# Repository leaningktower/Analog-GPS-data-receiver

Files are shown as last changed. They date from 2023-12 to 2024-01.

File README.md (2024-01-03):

Pasted Graphic

The picture above shows a pure analog Global Positioning System (GPS) data receiver that can receive the Navigation (NAV) Message from the GPS satellite. The receiver is a dual conversion receiver that includes five homemade PCB boards. A tinyFPGA is used for generating the Coarse Acquisition (C/A) code which retrieve the direct-sequence spread spectrum (DSSS) GPS signal submerged below the thermal noise level.

I was originally motivated by the works [1, 2] of Matjaz Vidmar (S53MV) and Andrew Holme. Both of the receivers are based on the 1-bit analog-to-digital converter (ADC) structure that uses on a single comparator that greatly the hardware of the design. The receiver of S53MV was built more than 30 years ago, based on a digital signal processor (DSP) that is made from fully discreet logic chips and a MC68010 processor. And the receiver of Andrew Holme is based on FPGA with a Forth-like Embedded CPU and a Raspberry Pi in charge of the fast Fourier transform (FFT) to speed up the satellite tracking process. Both two projects include great amount of minor details in software make them a bit daunted to the people who wants to learn from it and build their own receiver.

Another impressive analog GPS receiver comes from the book [3] of Dan Doberstein. In the Chapter 7 of this book, he provides a very detailed description of the GPS100SC receiver, which is a single channel data receiver and you can still literally build four of these receivers and find out your position! However, the receiver is not fully open sourced but makes me feel excited to build my own receiver from scratch. As a fan of analog electronics, it is also a fun project!

### Hardware Architecture

Pasted Graphic 1

The block diagram of the receiver is shown above. The receiver includes 5 different parts, the 1st mixer board, 1st LO board, 2nd mixer and correlation board, IF signal processing board and FPGA interfacing board (not shown). They are indicated by the dashed blocks in the diagram.

A commercial GPS antenna with internal amplifier and filters is used that can be easily find on AliExpress and Amazon. The first IF is set to around 60 MHz, which is relatively high to avoid the interference between antenna and local oscillator with poor shielding. LNA (BGA420) is placed before the 1st mixer (MAX2680) to decrease the noise figure of the receiver with a long coax cable between the antenna and receiver.

The 1st LO is based on an old fashioned integer-N frequency synthesiser (ADF4113) and discreet VCO (YSGM151708). Any frequency error caused by integer-N can be easily compensated by using a VCXO as the frequency reference. Further more, the VCXO also provides the frequency scan and the doppler frequency tracking of this receiver.

A 4th order LC filter with ~10 MHz bandwidth is placed after the 1st mixer, which removes most of the LO leakage of the first mixer. The LNA after the 1st mixer is optional but it is necessary for the impedance matching of the 1st mixer’s output.  The 2nd IF is 10.7 MHz and use a random 48 MHz oscillator as the 2nd LO. Instead of single tone signal, the 2nd LO is modulated with the dithered C/A code using Tau dither method, which switches the C/A code between the early and late phase at a frequency around 166 Hz. When the local C/A code is synchronised to the received signal, the DSSS signal is demodulated in to a Binary Phase-shift keying (BPSK) signal with 50 Hz chip rate and recovered from the thermal noise level. The down converted 10.7 MHz 2nd IF signal is sent to a crystal filter with 1.8 kHz bandwidth centred at 10.699 MHz.

The IF signal processing is based on SA604/SA605 FM receiver chip. The GPS signal strength is around -50 dBm before the IF signal processing board, which is more than enough for this chip with 90 dB dynamic range. The IF limiter output is filtered and sent to the comparator for finding out the IF frequency and used for tracking the doppler shift. The limiter output is also sent to another 10.7 MHz crystal used for quadrature detector, which converts the phase flip of the BPSK signal to the pulses at audio output of the detector. On the other hand, the amplitude of the signal is indicated by the RSSI output, two comparators are used to determine whether the signal strength is strong enough for the code phase or doppler frequency locking. A 166 Hz active band-pass filter is used to tell the FPGA to slow down or speed up the NCO to synchronise the code phase.

### FPGA Architecture

**C/A code tracking/lock and NAV data recovery**

Pasted Graphic 3

The block diagram above shows the block diagram for the C/A code tracking and locking system. The system clock is 24.552 MHz, which is 24 times of the 1.023 MHz chip rate. When the system is unlocked, a 8 bit u/d counter continuous trigger the div by 23 input of the 5 bit ring counter. That gives the 1.023 MHz C/A code clock frequency deviated by 64 kHz / 256 / 24 = 10.4 Hz. This offset frequency helps the system find the correlation peak every 1023 / 10.4 = 98 second where 1023 is the length of the C/A code. When the system finds the correlation peak, the code lock signal is enabled and the the u/d counter is controlled by the XOR between the 166 Hz dither signal and dither induced AM signal from RSSI. The detailed description can be found in [3].

**Doppler tracking/lock**

Pasted Graphic 4

The block diagram of doppler tracking/lock is shown above. Due to the narrowband 10.7 MHz filter for finding the IF frequency, the doppler lock needs higher RSSI trigger level than the code lock and the system is only locked when both signals are enabled. When doppler lock is not enabled, the 6 bit counter continues over flowed with a rate of 200 / 64 = 3 Hz, which scan the PWM output from 0 to 1023 in 5 minutes, this serves as the doppler scan for corse finding the satellite doppler shift between -5 to 5 kHz. When both the doppler scan and code scan located around correct position, the RSSI will be high enough to enable both signal. When the doppler lock is enabled the 6 bit up/down counter is controlled by the magnitude comparator which compares the measured IF center frequency with the setting frequency, which is 10.699 MHz. Since the counter is reset every 1/25 second, the 12 bit frequency counter will be overflowed 104 times and gives a final reading around 1976. A slightly different frerqnency is used in the receiver considering the best sensitivity of the quadrature detector circuit, which is determined by the center frequency of the quartz crystal being used.

### Detailed schematic

I made some small modifications to the circuit and the plots below gives the schematic that is updated in real design, which may show minor difference to the files in the folder.

Pasted Graphic 6
First mixer and preamp  

The transistor Q1 and bias tee U1 provides the clean power supply to the active antenna, two low noise amplifier is placed before and after the mixer U3. The impedance matching network of the mixer is calculated by the S parameters given by the manufactor. The board convert the GPS signal from 1575.42 MHz to 58.7 MHz and provides a overall gain around 41 dB.

Pasted Graphic 7
Second mixer and correlator  

Two mixer is used for down converting and C/A code modulation of the LO signal. The maximum output power of U3 is only 0 dBm which is significant lower than the require LO power of 7 dBm, however this doesn’t seems to be a big problem and only add several dB loss to the system. Three JFET follower is used for monitoring the 1st IF, 2nd IF and 2nd LO, note that the drain and source is reversed in the schematic and PCB design. The value of C12 is used to tune the bandwidth of the filter, which needs additional tuning for different crystals.

Pasted Graphic 9
IF signal processing  

A 10.7 MHz crystal oscillator Y1 is used but it can be a normal ceramic filter since there is already a narrowband filter before IF signal processing board. The fast comparator U2 and the OpAmp U8 needs dual power supply and a negative voltage generator is built from the CMOS inverter U4. Note that the VEE pin of U8 is tied to ground in the PCB design.

Pasted Graphic 10
First local oscillator  

An ATtiny85 is used for configure the ADF4331 setting after power up. The potentiometer is used for coarse adjusting the out frequency and frequency can be externally tuned by the tuning voltage through the connector J1. The U5 amplifier is optional considering the tuning voltage range of the VCO. The output power of this board is around 0 dBm.

Pasted Graphic 11
FPGA interfacing   

This boards provides all the interconnect between the TinyFPGA and external circuits. Another ATtiny85 is used for communicating between the FPGA and external keyboard/display. The external keyboard is used to set the SVID of the satellite, centre IF frequency and initialised output value of PWM. It is also used to monitor the realtime PWM output setting and IF counter frequency. Note that the power supply of U5 is reversed in the PCB design.

### Result

The final success takes several weekends for trouble shooting. The most significant problem is cause by the interference of the 24.552 MHz system clock generator. Originally I was using a Si5351’s programmed output as the system clock, however it generates a bunch of tones within the bandwidth of sensitive GPS antenna. Since it is hard to find any crystal works at this frequency, a final solution is done by the decapping a 24.576 MHz crystal and modifying the frequency by a sharpie pen. It is also frequency stabilised through external temperature controller.

It usually takes several minutes to lock to a satellite. A digital voltage meter is added to the RSSI output of the SA615 for monitoring the signal strength. The background noise gives a RSSI output around 2 V and gives a reading between 2.3 to 3 V when it is locked to a satellite. I use another GPS receiver to determine the SVID of the satellite I could find. 

Pasted Graphic 14

The GPS signal at the 2nd IF monitoring port, which shows the demodulated GPS signal recovered from the thermal noise background.

Pasted Graphic 13

The NAV data output (yellow) and quadrature detector output (cyan) of the GPS data receiver.

______________________________________________________________________________________________________________
References:

[1] GPS/GLONASS receiver by Matjaž Vidmar, S53MV; https://lea.hamradio.si/~s53mv/navsats/theory.html

[2] Homemade GPS Receiver by Andrew Holme; http://www.aholme.co.uk/GPS/Main.htm

[3] PRINCIPLES OF GPS RECEIVERS - A HARDWARE APPROACH by Dan Doberstein; http://www.dkdinst.com/gpstxt.html

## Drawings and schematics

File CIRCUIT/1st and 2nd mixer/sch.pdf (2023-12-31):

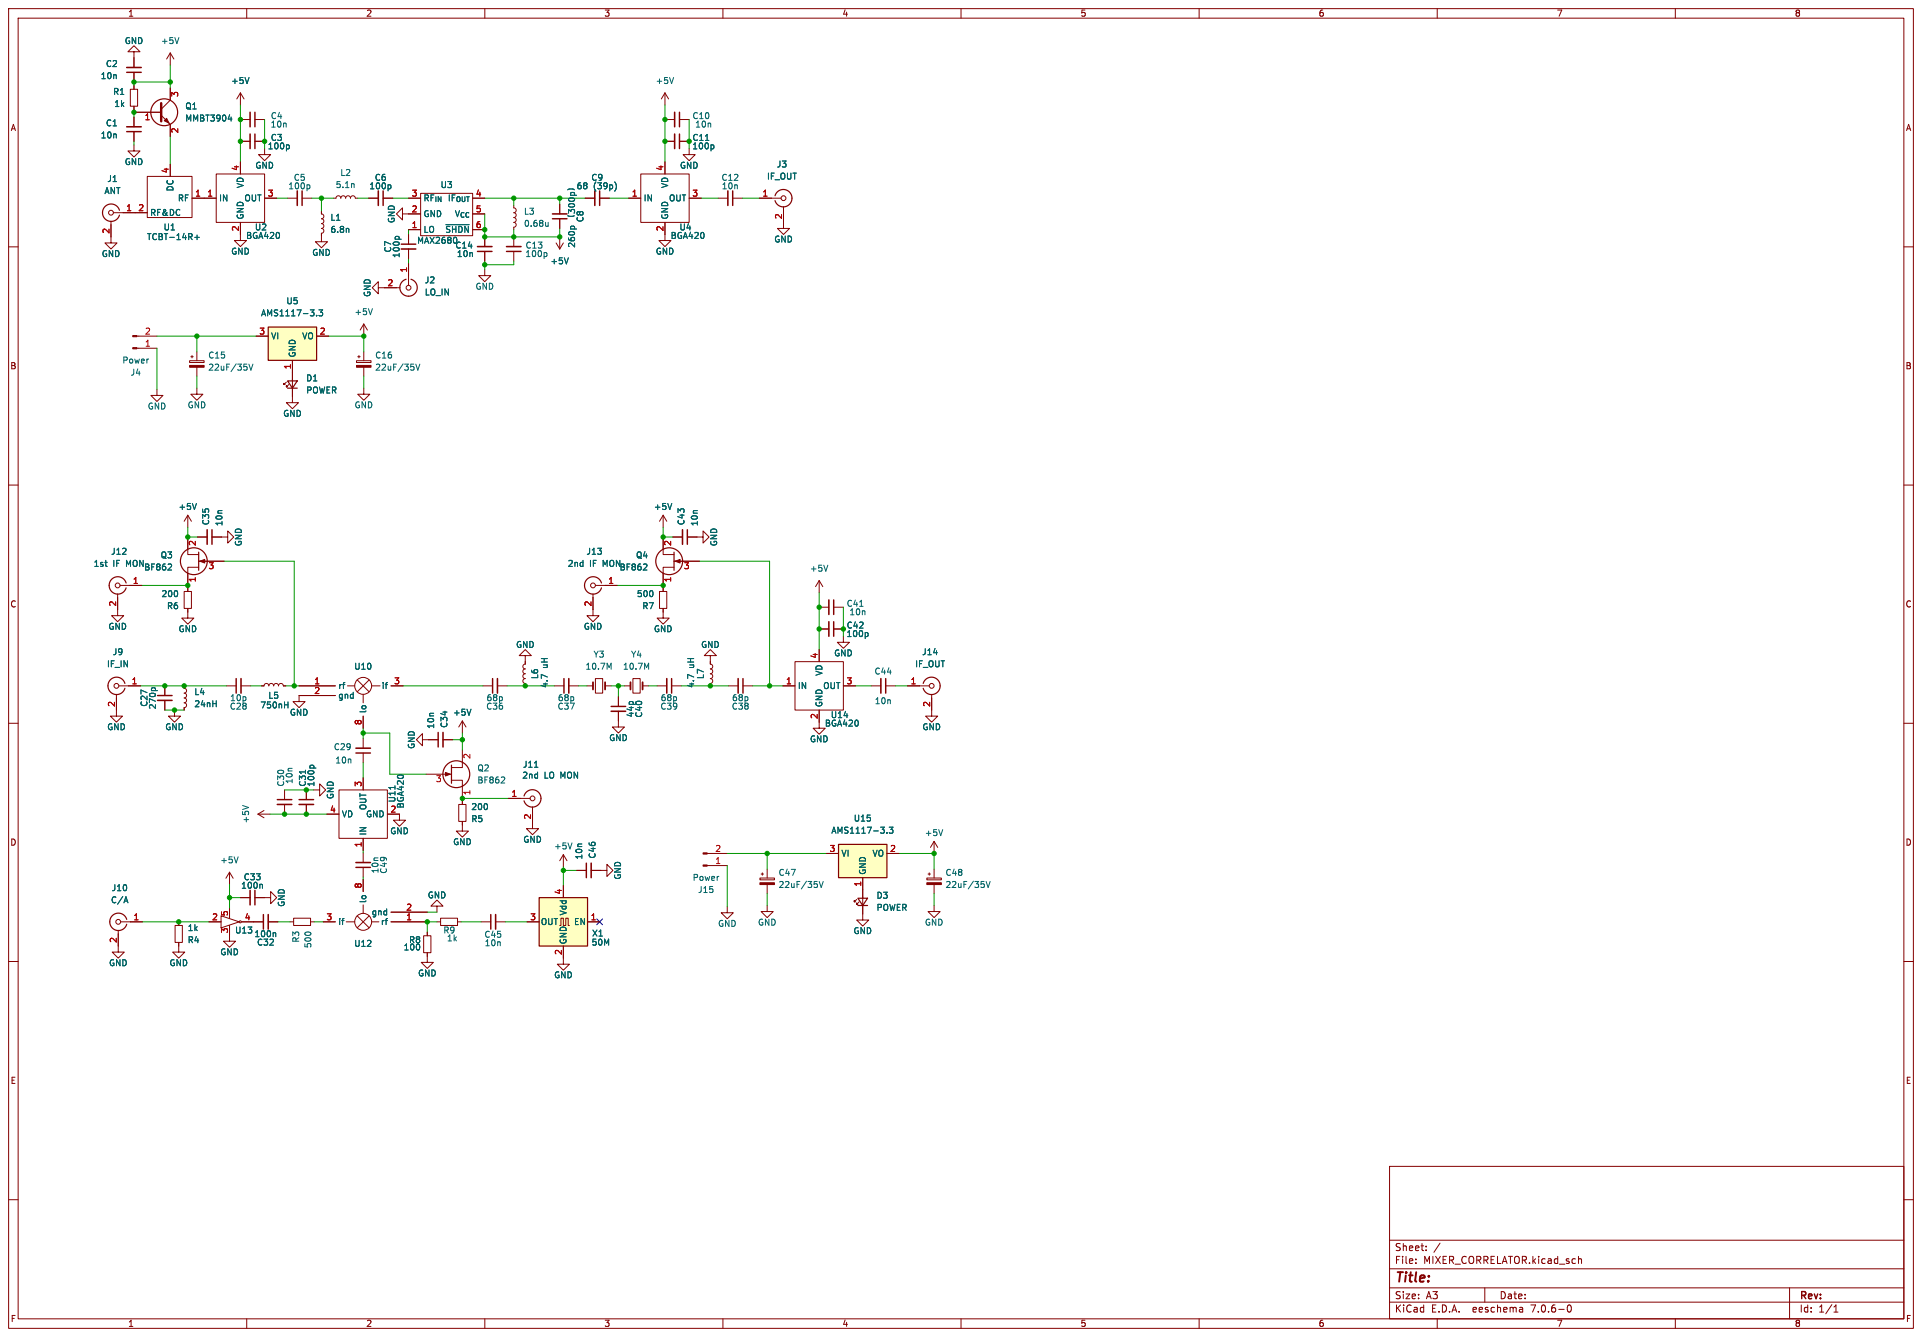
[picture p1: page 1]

if 3 lo 8 U10 GND GND 12

2nd IF MON 1 2 GND L6 4.7 uH

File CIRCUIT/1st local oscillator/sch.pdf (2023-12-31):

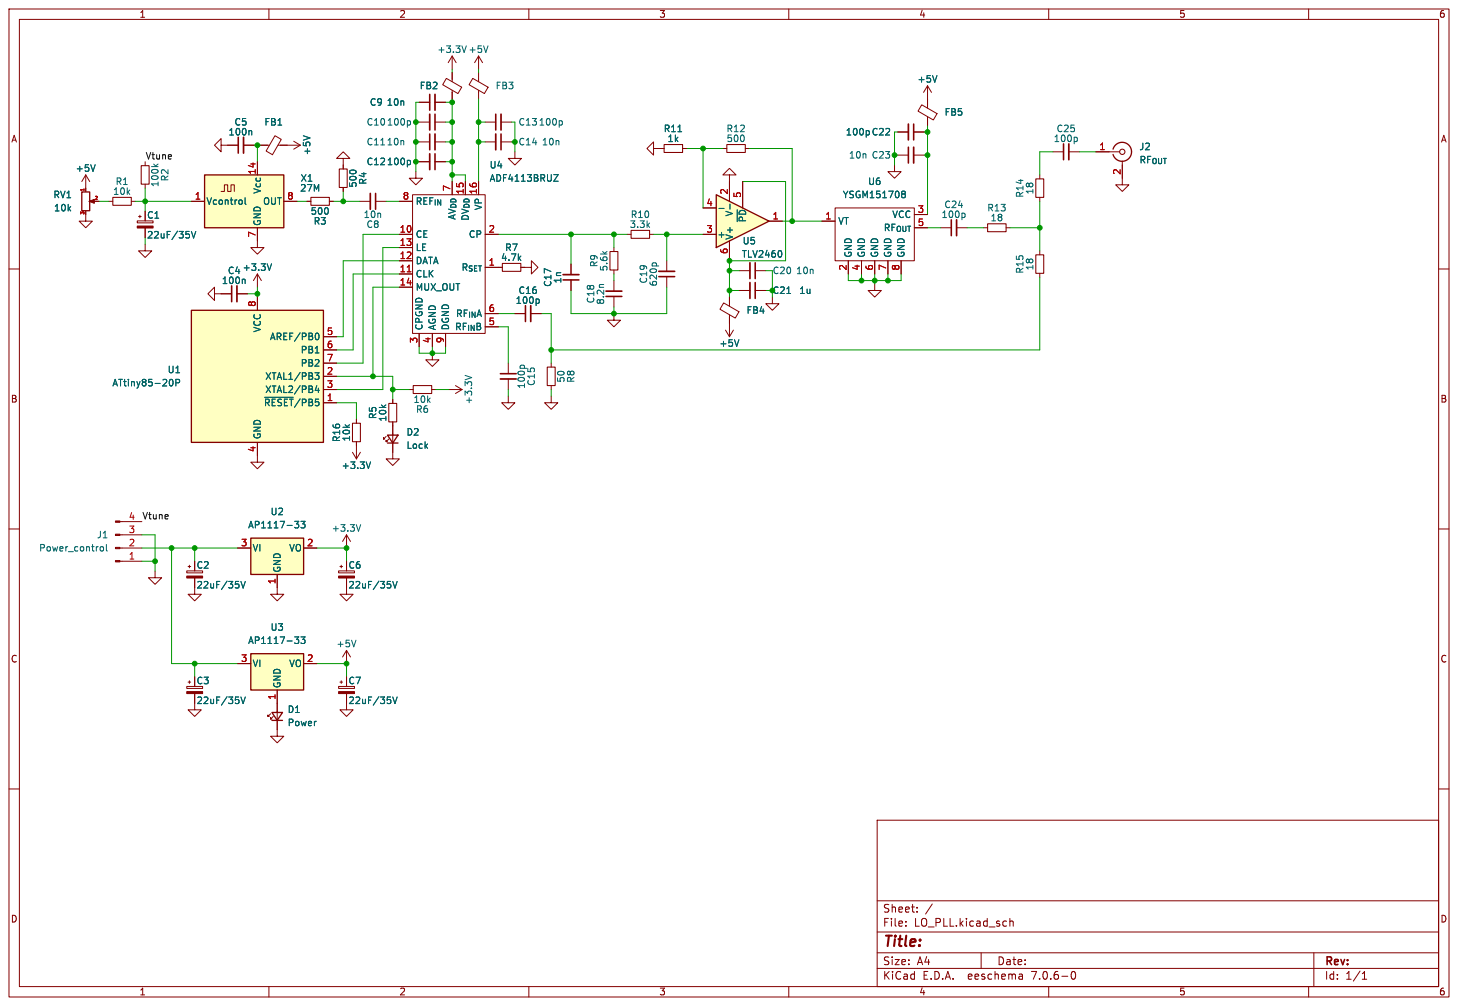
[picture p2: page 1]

4 RF_{IN}B5 RF_{IN}A6 AV_{DD} 7 REF_{IN} 8 DGND

Id: 1/1 Title: File: LO_PLL.kicad_sch Sheet: /

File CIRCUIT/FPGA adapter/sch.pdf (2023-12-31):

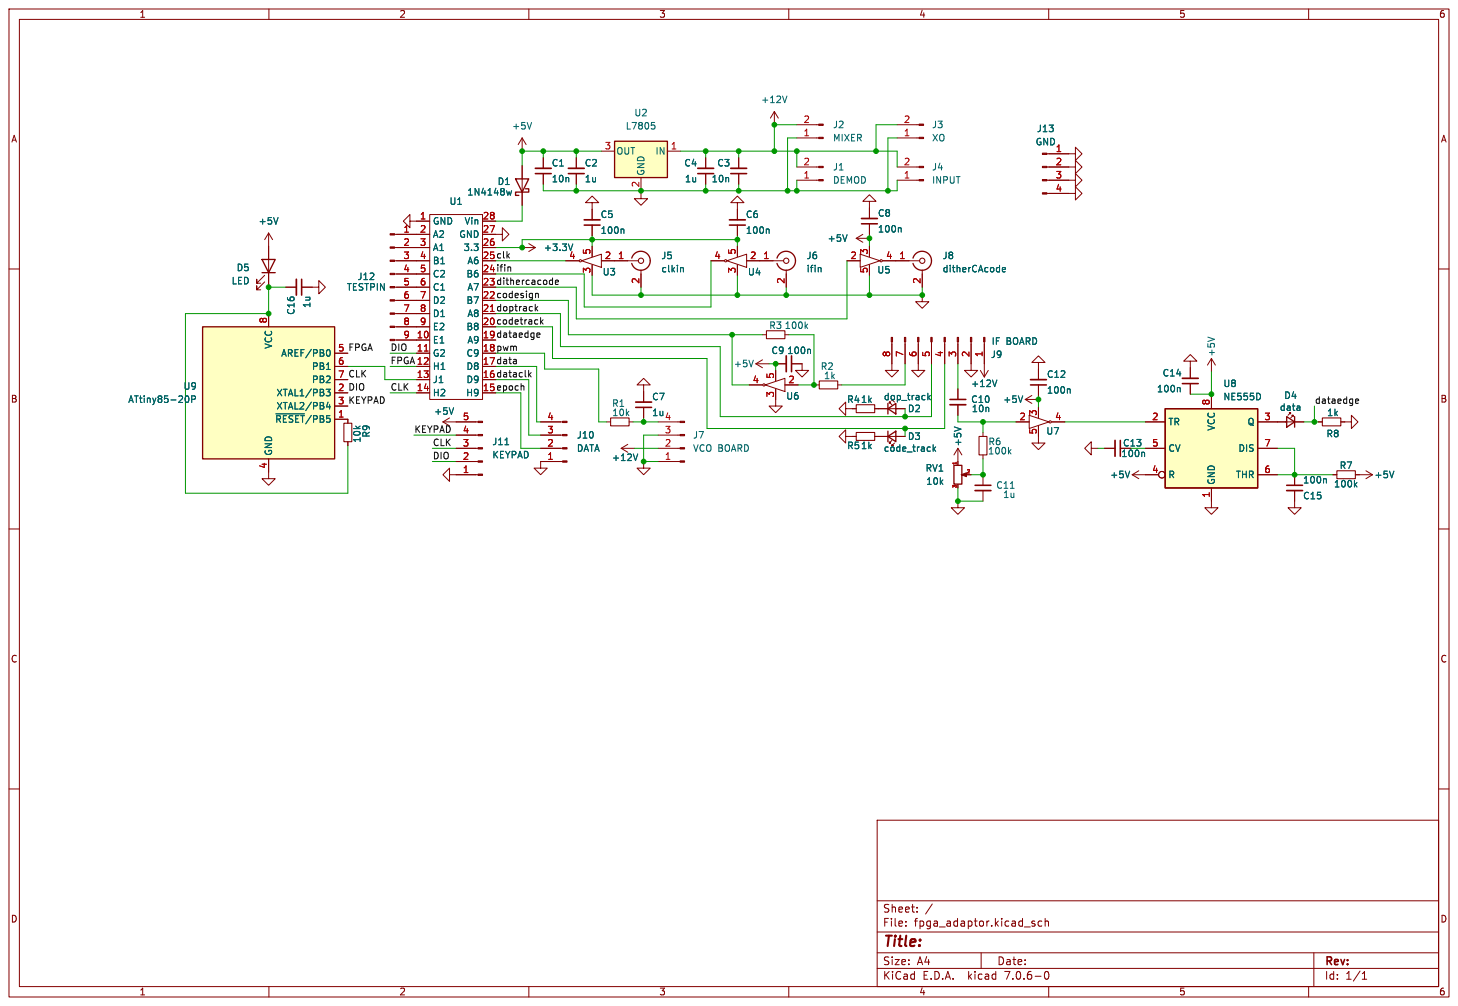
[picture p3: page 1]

Id: 1/1 Title: File: fpga_adaptor.kicad_sch Sheet: /

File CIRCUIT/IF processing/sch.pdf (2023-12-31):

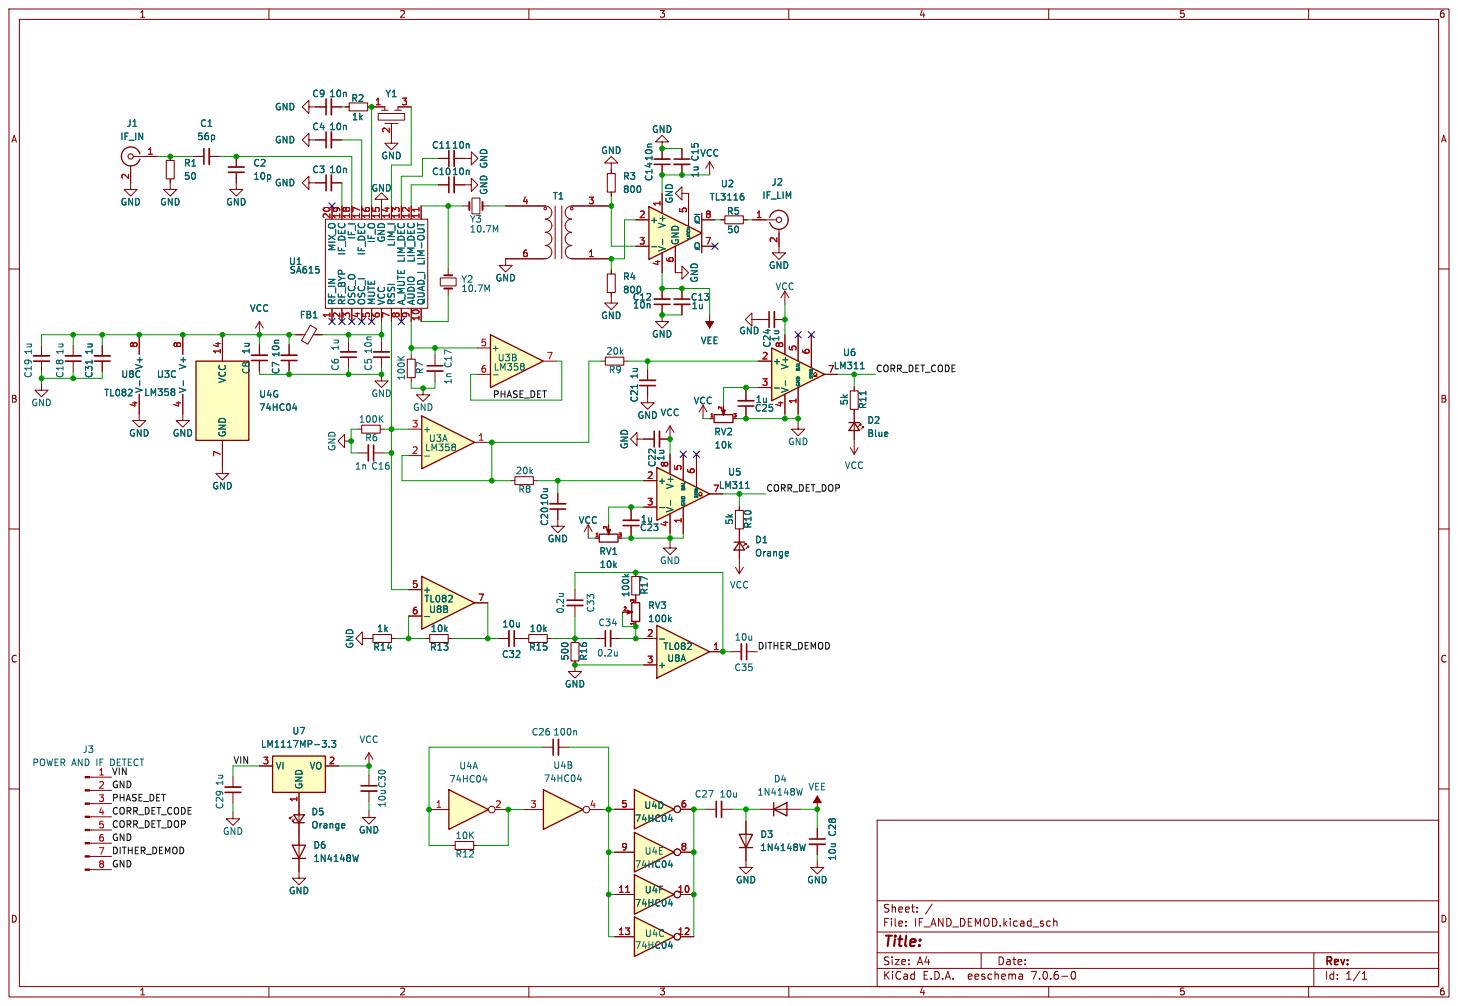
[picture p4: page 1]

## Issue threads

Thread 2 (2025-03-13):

some componets values are missing

zkf0100007, 2025-03-13:
Hi,

I want to build a reciever following your amazing project.
I found some componets values are missing.
U10, U12 in 2nd mixer
Y1 in IF processing
U3-U6 in FPGA adapter
Could you give me the exact values of those componets?

Thanks!

zkf0100007, 2025-03-14:
mixer is SRA-1+

leaningktower, 2025-03-14:
The mixer, as shown in the schematic, is SBL-1-1, SRA-1 could work.

Y1, as also mentioned in the description, can be the normal 10.7 MHz ceramic filter in FM radio (10M15A used here).

All the single inverters are 74LVC1G04.

zkf0100007, 2025-03-15:
Thanks for your reply!

Closed 2025-03-15.

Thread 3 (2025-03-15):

Some problem on schematic

zkf0100007, 2025-03-15:
Hi,

I am confused abuout the following nots:

1.note that the drain and source is reversed in the schematic and PCB design
I checked schematic and PCB, S is connected to a resistor to GND, D is connected to +5V.
I think it is OK.

2.Note that the VEE pin of U8 is tied to ground in the PCB design
Should I tied VEE pin of U8 to ground or -5v?

3.Note that the power supply of U5 is reversed in the PCB design
Should I tied pin 5 of U5 to ground or +5v?

Thanks!

leaningktower, 2025-03-15:
Hi, I think I already mentioned most of the small errors in the main text and there might be additional errors that easy to find out. I don't think it is necessary to answer your detailed question one by one since anyone who wants to refer or reproduce this design should have enough knowledge to do troubleshooting by them selves. Thank you!

zkf0100007, 2025-03-16:
OK
Thank you!

Closed 2025-03-16.

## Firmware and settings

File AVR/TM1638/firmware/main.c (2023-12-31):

//                  +-\/-+
// Ain0 (D 5) PB5  1|o   |8  Vcc
// Ain3 (D 3) PB3  2|    |7  PB2 (D 2) Ain1
// Ain2 (D 4) PB4  3|    |6  PB1 (D 1) pwm1
//            GND  4|    |5  PB0 (D 0) pwm0
//                  +----+

#define F_CPU 8000000

//PINS
//#define TWI_SDA_PIN    PB0
//#define TWI_SCL_PIN    PB1
//#define TWI_CSN_PIN    PB2
//#define FPGA_EN        PB3
//#define FPGA_DATA_OUT  PB4

#define TWI_SDA_PIN    PB3
#define TWI_SCL_PIN    PB2
#define TWI_CSN_PIN    PB4
#define FPGA_CSN_PIN   PB0
#define FPGA_SDI_PIN   PB1
#define FPGA_SDO_PIN   PB3
#define FPGA_SCL_PIN   PB2

//KEYS
#define key_na         0
#define key7           1 
#define key8           2
#define key9           3
#define key_page       4
#define key4           5
#define key5           6
#define key6           7
#define key_digit      8
#define key1           9
#define key2           10
#define key3           11
#define key_plus       12
#define key0           13
#define key_cancel     14
#define key_enter      15
#define key_minus      16

//FSM
#define S_IDLE         0
#define S_CSET         1
#define S_FSET         2
#define S_VSET         3
#define S_VDIS         4
#define S_FDIS         5
#define S_SET_IN       6

#include <avr/io.h>  
#include <avr/interrupt.h>
#include <util/delay.h>
#include "setup.c"

int main(void) {
    // enable SPI
    SoftSpiMasterInit(KEYBOARD);
    SoftSpiMasterInit(FPGA);
    // wait
    _delay_ms(10); 
    // display intensity set
    TM1638_enable(0); 
    // finite state machine
    while(1) {
        //loop here!
        //key
        keybuff_p = keybuff;
        keybuff = TM1638_KEY();
        //menu
        if(STATE == S_IDLE){
	        idlecode();
        }
        else if(STATE == S_CSET){
                csetcode();
        }
        else if(STATE == S_FSET){
                fsetcode();
        }
        else if(STATE == S_VSET){
                vsetcode();
        }
        else if(STATE == S_VDIS){
                vdiscode();
        }
        else if(STATE == S_FDIS){
                fdiscode();
        }
        else if(STATE == S_SET_IN){
                setincode();
        }
        else{
                STATE = S_IDLE;	
        }
        _delay_ms(50);
        ch_rcv = FPGA_update(STATE);
        _delay_ms(50);  
        //TM1638_DISPLAY(STATE, 2); 
    }
    SoftSpiMasterDeInit(KEYBOARD);
    SoftSpiMasterDeInit(FPGA);	 
    return 0;    
}

void idlecode(void) {
        if (keybuff == key_na) {
                STATE = S_IDLE;
                TM1638_STRING("gpsrcv"); 
        }
        else if (keybuff == key_page) {
                STATE = S_CSET;
                TM1638_STRING("svidset");
                _delay_ms(2000);
        }
        else {
        } 
        //TM1638_DISPLAY(keybuff, 2);
}

void keymod(uint32_t lowlim, uint32_t highlim) {
        if (config == 0) {
                n_set = n_channel;
        }
        else if (config == 1) {
                n_set = n_freq;
        }
        else if (config == 2) {
                n_set = n_vco;
        }
        else {
        }
        uint32_t mul = 1;
        for (uint8_t i = 0; i < digit_mod; i++) {
                mul = mul * 10;
        }
        if (keybuff == key_minus) {
                if (n_set >= mul) {
                        n_set = n_set - mul;
                }
        } 
        else if (keybuff == key_plus){
                if (n_set + mul <= 99999999) {
                        n_set = n_set + mul;
                }
        }
        else {
        }
        mul = 10;
        uint8_t d_count = 1;
        for (uint8_t i = 0; i < 8; i++) {
                if((n_set < mul) && (n_set >= mul / 10))    d_count = i + 1;
                mul = mul * 10;
        } 
        TM1638_enable(7); 
        TM1638_DISPLAY(n_set, d_count);
        _delay_ms(50); 
        if((n_set >= lowlim) && (n_set <= highlim)) {
                if (config == 0) {
                        n_channel = n_set;
                }
                else if (config == 1) {
                        n_freq = n_set;
                }
                else if (config == 2) {
                        n_vco = n_set;
                }
                else {
                }
        } else {
                TM1638_enable(0);
                TM1638_STRING("err");
                _delay_ms(500); 
        }
} 


void csetcode(void) {
        config = 0;
        keylow = 1;
        keyhigh = 32;
        TM1638_enable(0);
        TM1638_DISPLAY(n_channel, 2);
        if (keybuff == key_na) {
                STATE = S_CSET;
        }
        else if (keybuff == key_page) {
                STATE = S_FSET;
                TM1638_STRING("freqset");
                _delay_ms(2000);
        }
        else if (keybuff == key_enter) {
                STATE = S_SET_IN;
                n_set = 0;
                digit_cnt = 1;
                TM1638_STRING("set");
                _delay_ms(500);
        }
        else if ((keybuff == key_digit) && (keybuff_p == key_na)) {
                if(digit_mod < 8) {
                        digit_mod = digit_mod + 1; 
                } else {
                        digit_mod = 0;
                }
        }
        else if ((keybuff == key_plus) || (keybuff == key_minus)) {
                keymod(keylow, keyhigh);
        }
        else { 
        } 
}

void fsetcode(void) {
        config = 1;
        keylow = 0;
        keyhigh = 4095;
        TM1638_enable(0);
        TM1638_DISPLAY(n_freq, 4);
        if (keybuff == key_na) {
                STATE = S_FSET;
        }
        else if (keybuff == key_page) {
                STATE = S_VSET;
                TM1638_STRING("vcoset");
                _delay_ms(2000);
        }
        else if (keybuff == key_enter) {
                STATE = S_SET_IN;
                n_set = 0;
                digit_cnt = 1;
                TM1638_STRING("set");
                _delay_ms(500);
        }
        else if ((keybuff == key_digit) && (keybuff_p == key_na)) {
                if(digit_mod < 8) {
                        digit_mod = digit_mod + 1; 
                } else {
                        digit_mod = 0;
                }
        }
        else if ((keybuff == key_plus) || (keybuff == key_minus)) {
                keymod(keylow, keyhigh);
        }
        else {
        } 
}

void vsetcode(void) {
        config = 2;
        keylow = 0;
        keyhigh = 1023;
        TM1638_enable(0);
        TM1638_DISPLAY(n_vco, 4);
        if (keybuff == key_na) {
                STATE = S_VSET;
        }
        else if (keybuff == key_page) {
                STATE = S_VDIS;
                TM1638_STRING("vcovalue");
                _delay_ms(2000);
        }
        else if (keybuff == key_enter) {
                STATE = S_SET_IN;
                n_set = 0;
                digit_cnt = 1;
                TM1638_STRING("set");
                _delay_ms(500);
        }
        else if ((keybuff == key_digit) && (keybuff_p == key_na)) {
                if(digit_mod < 8) {
                        digit_mod = digit_mod + 1; 
                } else {
                        digit_mod = 0;
                }
        }
        else if ((keybuff == key_plus) || (keybuff == key_minus)) {
                keymod(keylow, keyhigh);
        }
        else {
        } 
}

void vdiscode(void) {
        TM1638_enable(0);
        TM1638_DISPLAY(n_pwm, 4);
        if (keybuff == key_na) {
                STATE = S_VDIS;
        }
        else if (keybuff == key_page) {
                STATE = S_FDIS;
                TM1638_STRING("iffreq");
                _delay_ms(2000);
        }
        else {
        } 
}

void fdiscode(void) {
        TM1638_enable(0);
        TM1638_DISPLAY(f_dop, 4);
        if (keybuff == key_na) {
                STATE = S_FDIS;
        }
        else if (keybuff == key_page) {
                STATE = S_CSET;
                TM1638_STRING("svidset");
                _delay_ms(2000);
        }
        else {
        } 
}

void setincode(void) {        
        TM1638_enable(7);
        if (keybuff == key_na) {
                STATE = S_SET_IN;
        }
        else if ((keybuff == key_enter) && (keybuff_p == key_na)) {
                if((n_set >= keylow) && (n_set <= keyhigh)) {
                        if (config == 0) {
                                n_channel = n_set;
                        }
                        else if (config == 1) {
                                 n_freq = n_set;
                        }
                        else if (config == 2) {
                                 n_vco = n_set;
                        }
                        else {
                        }
                } else {
                        TM1638_enable(0);
                        TM1638_STRING("err");
                        _delay_ms(500); 
                }
                  
                STATE = config + 1;
        }
        else if ((key_decoder[keybuff] != 0xff) && ((keybuff_p == key_na) || (keybuff_p == key_enter))) {
                n_set = key_decoder[keybuff] + n_set * 10;
                TM1638_enable(7); 
                TM1638_DISPLAY(n_set, digit_cnt);
                digit_cnt = digit_cnt + 1; 
        }
        else if ((keybuff == key_cancel) && (keybuff_p == key_na)) {
                n_set = n_set / 10;
                digit_cnt = digit_cnt - 1; 
                TM1638_enable(7); 
                TM1638_DISPLAY(n_set, digit_cnt - 1);
        }
        else {
        } 
}

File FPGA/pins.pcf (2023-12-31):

###############################################################################
#
# TinyFPGA BX constraint file (.pcf)
#
###############################################################################
#
# Copyright (c) 2018, Luke Valenty
# All rights reserved.
#
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
# THIS SOFTWARE IS PROVIDED BY THE COPYRIGHT HOLDERS AND CONTRIBUTORS "AS IS" AND
# ANY EXPRESS OR IMPLIED WARRANTIES, INCLUDING, BUT NOT LIMITED TO, THE IMPLIED
# WARRANTIES OF MERCHANTABILITY AND FITNESS FOR A PARTICULAR PURPOSE ARE
# DISCLAIMED. IN NO EVENT SHALL THE COPYRIGHT OWNER OR CONTRIBUTORS BE LIABLE FOR
# ANY DIRECT, INDIRECT, INCIDENTAL, SPECIAL, EXEMPLARY, OR CONSEQUENTIAL DAMAGES
# (INCLUDING, BUT NOT LIMITED TO, PROCUREMENT OF SUBSTITUTE GOODS OR SERVICES;
# LOSS OF USE, DATA, OR PROFITS; OR BUSINESS INTERRUPTION) HOWEVER CAUSED AND
# ON ANY THEORY OF LIABILITY, WHETHER IN CONTRACT, STRICT LIABILITY, OR TORT
# (INCLUDING NEGLIGENCE OR OTHERWISE) ARISING IN ANY WAY OUT OF THE USE OF THIS
# SOFTWARE, EVEN IF ADVISED OF THE POSSIBILITY OF SUCH DAMAGE.
#
# The views and conclusions contained in the software and documentation are those
# of the authors and should not be interpreted as representing official policies,
# either expressed or implied, of the <project name> project.
#
###############################################################################

####
# TinyFPGA BX information: https://github.com/tinyfpga/TinyFPGA-BX/
####

# Left side of board
#set_io --warn-no-port CAcode A2
#set_io --warn-no-port ditherCAcode A1
#set_io --warn-no-port epoch B1
#set_io --warn-no-port dataclk C2
#set_io --warn-no-port dither C1
#set_io --warn-no-port codeclk D2
#set_io --warn-no-port dataclkrst D1
#set_io --warn-no-port codesign E2
#set_io --warn-no-port doptrack E1
#set_io --warn-no-port codetrack G2
#set_io --warn-no-port ifin H1
#set_io --warn-no-port pwm J1
#set_io --warn-no-port clk H2

#set_io --warn-no-port CAcode         A2
#set_io --warn-no-port ditherCAcode_m A1
#set_io --warn-no-port dither         B1
#set_io --warn-no-port epoch_m        C2
#set_io --warn-no-port codeclk        C1
#set_io --warn-no-port dataclk_m      D2
#set_io --warn-no-port data_m         D1
#set_io --warn-no-port codeNCOud      E2
set_io --warn-no-port PIN_1          A2
set_io --warn-no-port PIN_2          A1
set_io --warn-no-port PIN_3          B1
set_io --warn-no-port PIN_4          C2
set_io --warn-no-port PIN_5          C1
set_io --warn-no-port PIN_6          D2
set_io --warn-no-port PIN_7          D1
set_io --warn-no-port PIN_8          E2
set_io --warn-no-port rst            E1
set_io --warn-no-port mosi           G2
set_io --warn-no-port en             H1
set_io --warn-no-port miso           J1
set_io --warn-no-port sck            H2

# Right side of board
#set_io --warn-no-port setin[3] H9
#set_io --warn-no-port setin[2] D9
#set_io --warn-no-port setin[1] D8
#set_io --warn-no-port setin[0] C9
#set_io --warn-no-port setin[7] A9
#set_io --warn-no-port setin[6] B8
#set_io --warn-no-port setin[5] A8
#set_io --warn-no-port setin[4] B7
#set_io --warn-no-port keydop A7
#set_io --warn-no-port keysat B6
#set_io --warn-no-port rst A6

set_io --warn-no-port epoch        H9
set_io --warn-no-port dataclk      D9
set_io --warn-no-port data         D8
set_io --warn-no-port pwm          C9
set_io --warn-no-port dataclkrst   A9
set_io --warn-no-port codetrack    B8
set_io --warn-no-port doptrack     A8
set_io --warn-no-port codesign     B7
set_io --warn-no-port ditherCAcode A7
set_io --warn-no-port ifin         B6
set_io --warn-no-port clk          A6

# SPI flash interface on bottom of board
set_io --warn-no-port SPI_SS  F7
set_io --warn-no-port SPI_SCK G7
set_io --warn-no-port SPI_IO0 G6
set_io --warn-no-port SPI_IO1 H7
set_io --warn-no-port SPI_IO2 H4
set_io --warn-no-port SPI_IO3 J8

# General purpose pins on bottom of board
set_io --warn-no-port PIN_25 G1
set_io --warn-no-port PIN_26 J3
set_io --warn-no-port PIN_27 J4
set_io --warn-no-port PIN_28 G9
set_io --warn-no-port PIN_29 J9
set_io --warn-no-port PIN_30 E8
set_io --warn-no-port PIN_31 J2

# LED
set_io --warn-no-port LED B3

# USB
set_io --warn-no-port USBP B4
set_io --warn-no-port USBN A4
set_io --warn-no-port USBPU A3

# 16MHz clock
set_io --warn-no-port clk0 B2 # input

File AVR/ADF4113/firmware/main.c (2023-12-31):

//                  +-\/-+
// Ain0 (D 5) PB5  1|o   |8  Vcc
// Ain3 (D 3) PB3  2|    |7  PB2 (D 2) Ain1
// Ain2 (D 4) PB4  3|    |6  PB1 (D 1) pwm1
//            GND  4|    |5  PB0 (D 0) pwm0
//                  +----+

#define F_CPU 1000000

//PINS

#define TWI_SDA_PIN    PB0
#define TWI_SCL_PIN    PB1
#define TWI_CSN_PIN    PB4
#define MUX            PB3
#define CE             PB2

#define CEPIN (1 << CE)


#include <avr/io.h>  
#include <avr/interrupt.h>
#include <util/delay.h>
#include "setup.c"

int main(void) {
    DDRB |= (1 << CE);
    PORTB &= ~CEPIN;
    
//    static const byte reg0[] = {0x93, 0xFE, 0x5D};
//    static const byte reg1[] = {0x20, 0x03, 0x70};
//    static const byte reg2[] = {0x15, 0xDE, 0x22};

    static const byte reg0[] = {0x93, 0xFE, 0x5D};
    static const byte reg1[] = {0x8C, 0x0A, 0x70};
    static const byte reg2[] = {0x15, 0xF9, 0x29};

    SoftSpiMasterInit();

    _delay_ms(100); 
    
    soft_spi_adf4113_write_bytes(reg0);
    soft_spi_adf4113_write_bytes(reg1);
    soft_spi_adf4113_write_bytes(reg2);


    PORTB |= CEPIN;
    
    while(1) {
    //loop here!
    }
    SoftSpiMasterDeInit();	 
    return 0;     
}
